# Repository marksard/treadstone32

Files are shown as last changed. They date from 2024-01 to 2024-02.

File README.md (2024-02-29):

# treadstone32
A 32-key compact keyboard project.  

This repository contains projects from rev2 onward. rev1, lite related projects can be found at the following links.  
[https://github.com/marksard/Keyboards/tree/master](https://github.com/marksard/Keyboards/tree/master)

# Completed example
GHZOivdbcAAUKvy

# Layout
ts40-in-m0ii040-case-concept

# Support software

QMK Firmware  
https://github.com/marksard/qmk_firmware/tree/own_build/keyboards/marksard/treadstone32/rev2

# Build guide

https://github.com/marksard/treadstone32/blob/main/documents/buildguide.md

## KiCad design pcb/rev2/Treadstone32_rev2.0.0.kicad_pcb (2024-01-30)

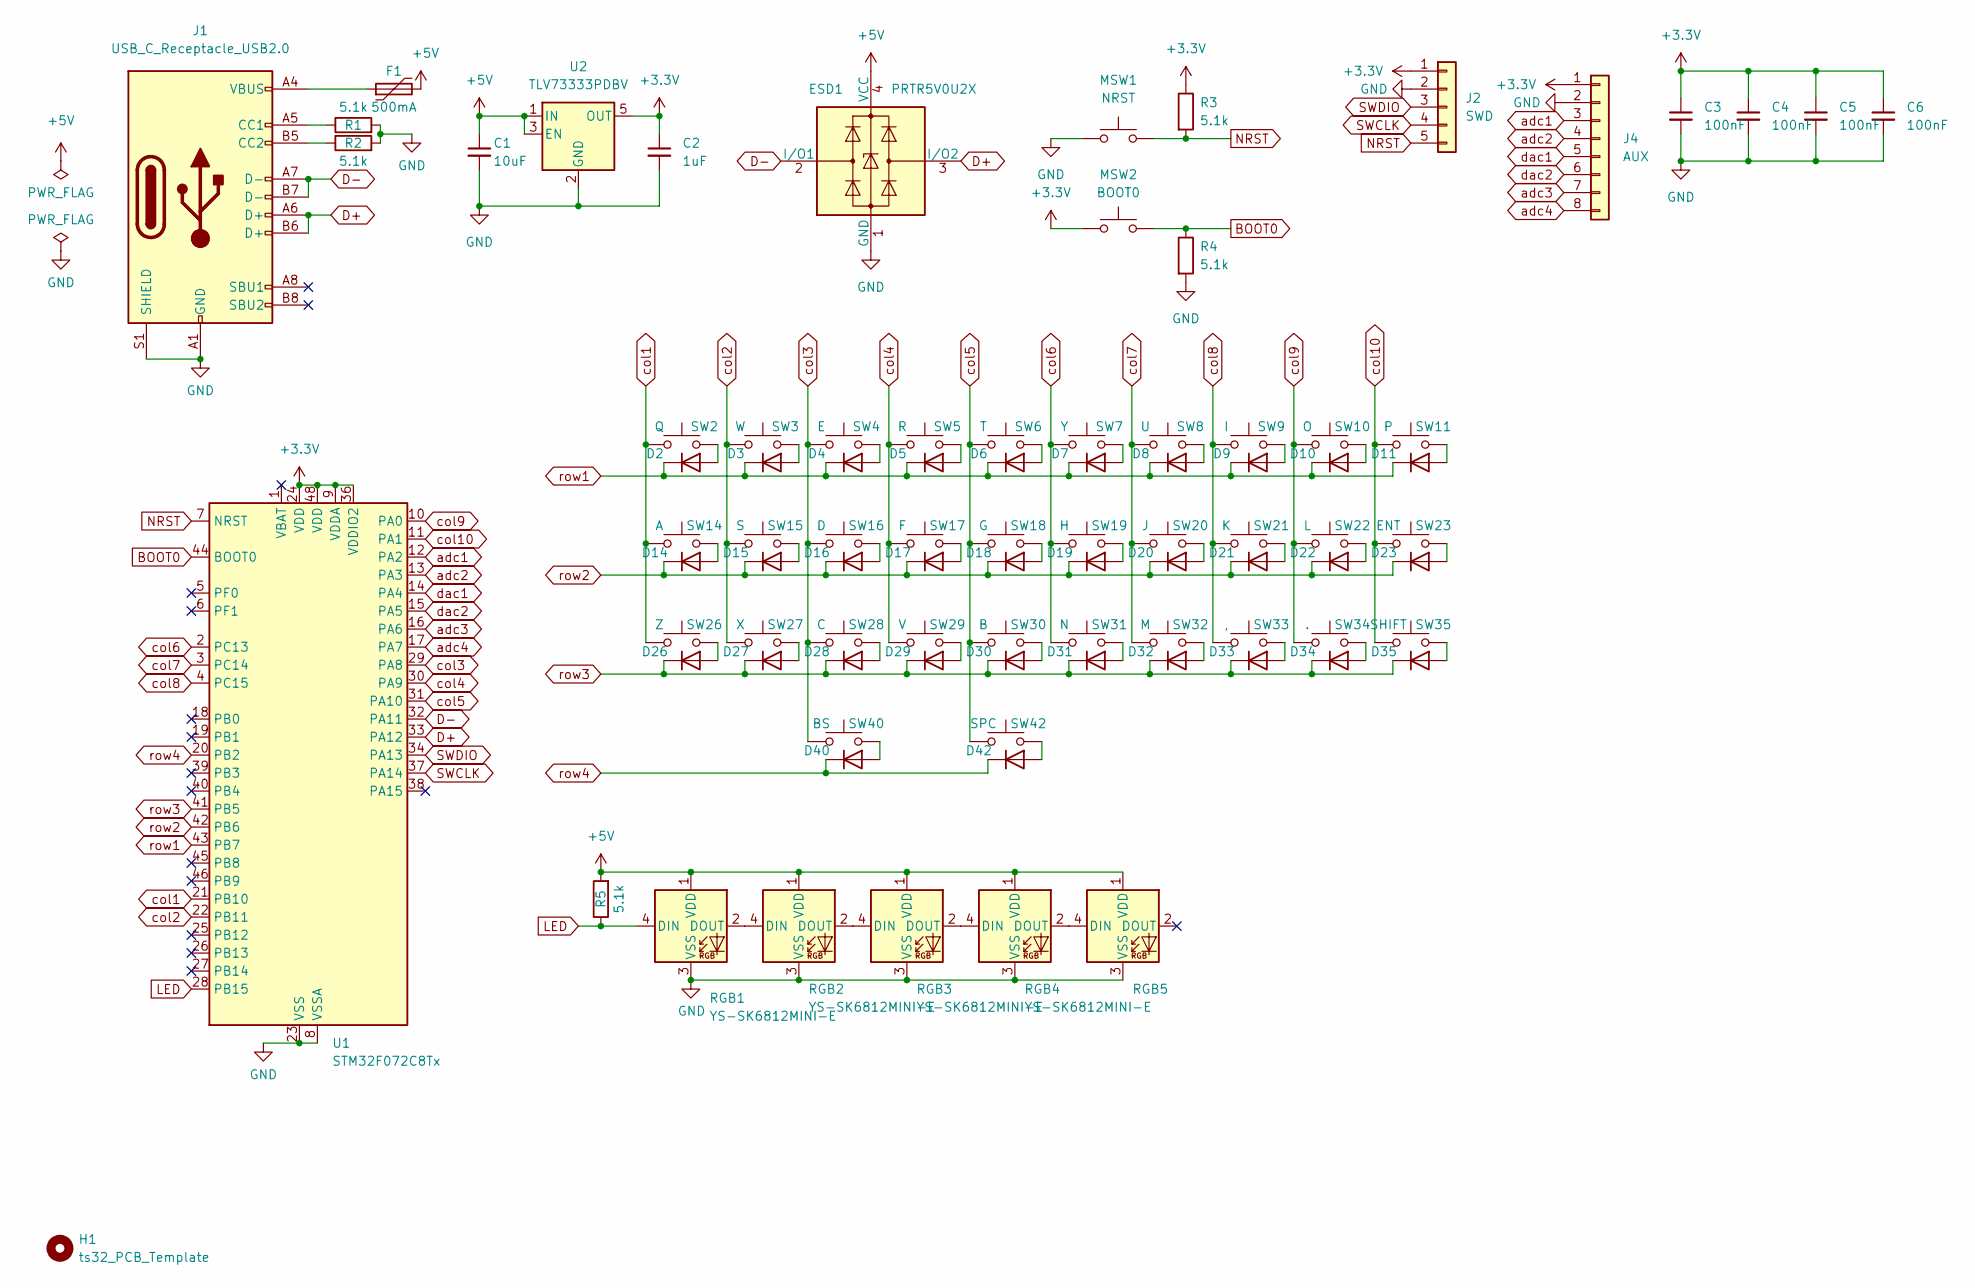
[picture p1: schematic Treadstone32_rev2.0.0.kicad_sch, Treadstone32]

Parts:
C1: 10uF; C_0603_1608Metric; LCSC C19702
C2: 1uF; C_0402_1005Metric; LCSC C52923
C3, C4, C5, C6: 100nF; C_0402_1005Metric; LCSC C1525
D2, D3, D4, D5, D6, D7, D8, D9, D10, D11, D14, D15, D16, D17, D18, D19, D20, D21, D22, D23, D26, D27, D28, D29, D30, D31, D32, D33, D34, D35, D40, D42: D; D_SOD-123; LCSC C81598
ESD1: PRTR5V0U2X; SOT-143; LCSC C12333
F1: 500mA; Fuse_0805_2012Metric; LCSC C261942
H1: ts32_PCB_Template; ts32_PCB_Template_v2.0.0
J1: USB_C_Receptacle_USB2.0; HRO-TYPE-C-31-M-13x; LCSC C2848619
J2: SWD; PinHeader_1x05_P2.54mm_Vertical
J4: AUX; PinHeader_1x08_P2.54mm_Vertical
MSW1: NRST; TVBP06-B043CB
MSW2: BOOT0; TVBP06-B043CB
R1, R2: 5.1k; R_0603_1608Metric; LCSC C23186
R3, R4: 5.1k; R_0402_1005Metric; LCSC C23186
R5: 5.1k; R_0603_1608Metric; LCSC C445832
RGB1, RGB2, RGB3, RGB4, RGB5: YS-SK6812MINI-E; YS-SK6812MINI-E_undergrow; LCSC C5378731
SW2: Q; MX-Hotswap-1U_F; LCSC C5156480
SW3: W; MX-Hotswap-1U_F; LCSC C5156480
SW4: E; MX-Hotswap-1U_F; LCSC C5156480
SW5: R; MX-Hotswap-1U_F; LCSC C5156480
SW6: T; MX-Hotswap-1U_F; LCSC C5156480
SW7: Y; MX-Hotswap-1U_F; LCSC C5156480
SW8: U; MX-Hotswap-1U_F; LCSC C5156480
SW9: I; MX-Hotswap-1U_F; LCSC C5156480
SW10: O; MX-Hotswap-1U_F; LCSC C5156480
SW11: P; MX-Hotswap-1U_F; LCSC C5156480
SW14: A; MX-Hotswap-1U_F; LCSC C5156480
SW15: S; MX-Hotswap-1U_F; LCSC C5156480
SW16: D; MX-Hotswap-1U_F; LCSC C5156480
SW17: F; MX-Hotswap-1U_F; LCSC C5156480
SW18: G; MX-Hotswap-1U_F; LCSC C5156480
SW19: H; MX-Hotswap-1U_F; LCSC C5156480
SW20: J; MX-Hotswap-1U_F; LCSC C5156480
SW21: K; MX-Hotswap-1U_F; LCSC C5156480
SW22: L; MX-Hotswap-1U_F; LCSC C5156480
SW23: ENT; MX-Hotswap-1U_F; LCSC C5156480
SW26: Z; MX-Hotswap-1U_F; LCSC C5156480
SW27: X; MX-Hotswap-1U_F; LCSC C5156480
SW28: C; MX-Hotswap-1U_F; LCSC C5156480
SW29: V; MX-Hotswap-1U_F; LCSC C5156480
SW30: B; MX-Hotswap-1U_F; LCSC C5156480
SW31: N; MX-Hotswap-1U_F; LCSC C5156480
SW32: M; MX-Hotswap-1U_F; LCSC C5156480
SW33: ,; MX-Hotswap-1U_F; LCSC C5156480
SW34: .; MX-Hotswap-1U_F; LCSC C5156480
SW35: SHIFT; MX-Hotswap-1U_F; LCSC C5156480
SW40: BS; MX-Hotswap-1U_F; LCSC C5156480
SW42: SPC; MX-Hotswap-1U_F; LCSC C5156480
U1: STM32F072C8Tx; LQFP-48_7x7mm_P0.5mm; LCSC C80488
U2: TLV73333PDBV; SOT-23-5; LCSC C134139

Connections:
+3.3V: C2.1, C3.1, C4.1, C5.1, C6.1, J2.1, J4.1, MSW2.1, R3.1, U1.9 (VDDA), U1.24 (VDD), U1.36 (VDDIO2), U1.48 (VDD), U2.5 (OUT)
+5V: C1.1, ESD1.4 (VCC), F1.2, R5.2, U2.1 (IN), U2.3 (EN); also elsewhere on the board
BOOT0: MSW2.2, R4.1, U1.44 (BOOT0)
D+: ESD1.3 (I/O2), J1.A6 (D+), J1.B6 (D+), U1.33 (PA12)
D-: ESD1.2 (I/O1), J1.A7 (D-), J1.B7 (D-), U1.32 (PA11)
GND: C1.2, C2.2, C3.2, C4.2, C5.2, C6.2, ESD1.1 (GND), J1.A1 (GND), J1.A12 (GND), J1.B1 (GND), J1.B12 (GND), J1.S1 (SHIELD), J2.2, J4.2, MSW1.1, R1.2, R2.2, R4.2, U1.8 (VSSA), U1.23 (VSS), U1.35 (VSS), U1.47 (VSS), U2.2 (GND); also elsewhere on the board
LED: R5.1, U1.28 (PB15); also elsewhere on the board
NRST: J2.5, MSW1.2, R3.2, U1.7 (NRST)
unnamed: D2.2 (A), SW2.2
unnamed: D3.2 (A), SW3.2
unnamed: D4.2 (A), SW4.2
unnamed: D5.2 (A), SW5.2
unnamed: D6.2 (A), SW6.2
unnamed: D7.2 (A), SW7.2
unnamed: D8.2 (A), SW8.2
unnamed: D9.2 (A), SW9.2
unnamed: D10.2 (A), SW10.2
unnamed: D11.2 (A), SW11.2
unnamed: D14.2 (A), SW14.2
unnamed: D15.2 (A), SW15.2
unnamed: D16.2 (A), SW16.2
unnamed: D17.2 (A), SW17.2
unnamed: D18.2 (A), SW18.2
unnamed: D19.2 (A), SW19.2
unnamed: D20.2 (A), SW20.2
unnamed: D21.2 (A), SW21.2
unnamed: D22.2 (A), SW22.2
unnamed: D23.2 (A), SW23.2
unnamed: D26.2 (A), SW26.2
unnamed: D27.2 (A), SW27.2
unnamed: D28.2 (A), SW28.2
unnamed: D29.2 (A), SW29.2
unnamed: D30.2 (A), SW30.2
unnamed: D31.2 (A), SW31.2
unnamed: D32.2 (A), SW32.2
unnamed: D33.2 (A), SW33.2
unnamed: D34.2 (A), SW34.2
unnamed: D35.2 (A), SW35.2
unnamed: D40.2 (A), SW40.2
unnamed: D42.2 (A), SW42.2
unnamed: F1.1, J1.A4 (VBUS), J1.A9 (VBUS), J1.B4 (VBUS), J1.B9 (VBUS)
unnamed: J1.A5 (CC1), R1.1
unnamed: J1.B5 (CC2), R2.1
SWCLK: J2.4, U1.37 (PA14)
SWDIO: J2.3, U1.34 (PA13)
adc1: J4.3, U1.12 (PA2)
adc2: J4.4, U1.13 (PA3)
adc3: J4.7, U1.16 (PA6)
adc4: J4.8, U1.17 (PA7)
col1: SW2.1, SW14.1, SW26.1, U1.21 (PB10)
col2: SW3.1, SW15.1, SW27.1, U1.22 (PB11)
col3: SW4.1, SW16.1, SW28.1, SW40.1, U1.29 (PA8)
col4: SW5.1, SW17.1, SW29.1, U1.30 (PA9)
col5: SW6.1, SW18.1, SW30.1, SW42.1, U1.31 (PA10)
col6: SW7.1, SW19.1, SW31.1, U1.2 (PC13)
col7: SW8.1, SW20.1, SW32.1, U1.3 (PC14)
col8: SW9.1, SW21.1, SW33.1, U1.4 (PC15)
col9: SW10.1, SW22.1, SW34.1, U1.10 (PA0)
col10: SW11.1, SW23.1, SW35.1, U1.11 (PA1)
dac1: J4.5, U1.14 (PA4)
dac2: J4.6, U1.15 (PA5)
row1: D2.1 (K), D3.1 (K), D4.1 (K), D5.1 (K), D6.1 (K), D7.1 (K), D8.1 (K), D9.1 (K), D10.1 (K), D11.1 (K), U1.43 (PB7)
row2: D14.1 (K), D15.1 (K), D16.1 (K), D17.1 (K), D18.1 (K), D19.1 (K), D20.1 (K), D21.1 (K), D22.1 (K), D23.1 (K), U1.42 (PB6)
row3: D26.1 (K), D27.1 (K), D28.1 (K), D29.1 (K), D30.1 (K), D31.1 (K), D32.1 (K), D33.1 (K), D34.1 (K), D35.1 (K), U1.41 (PB5)
row4: D40.1 (K), D42.1 (K), U1.20 (PB2)

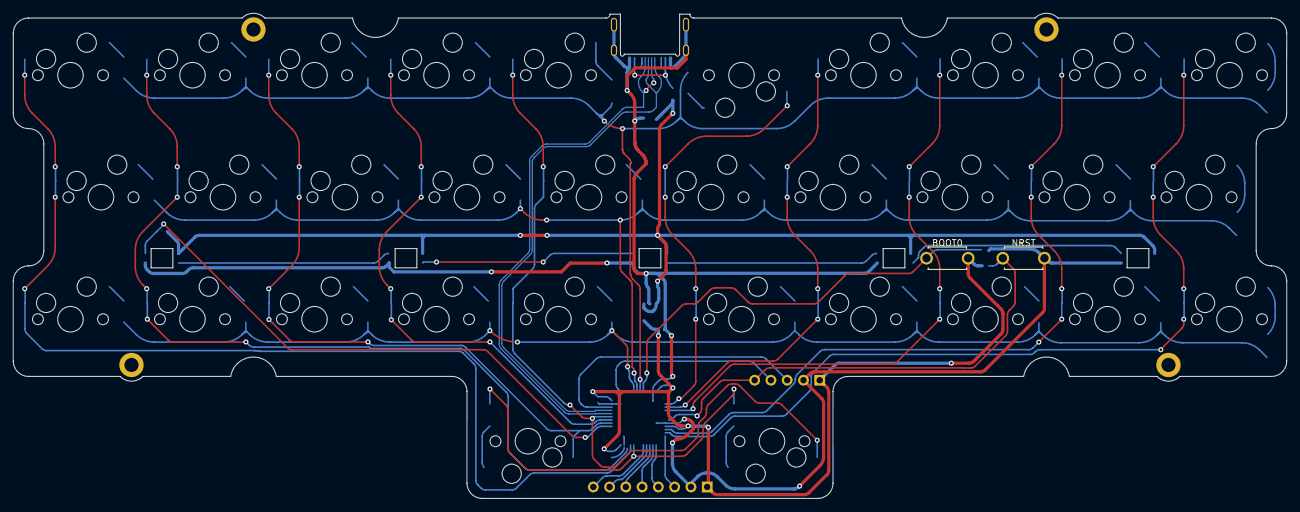
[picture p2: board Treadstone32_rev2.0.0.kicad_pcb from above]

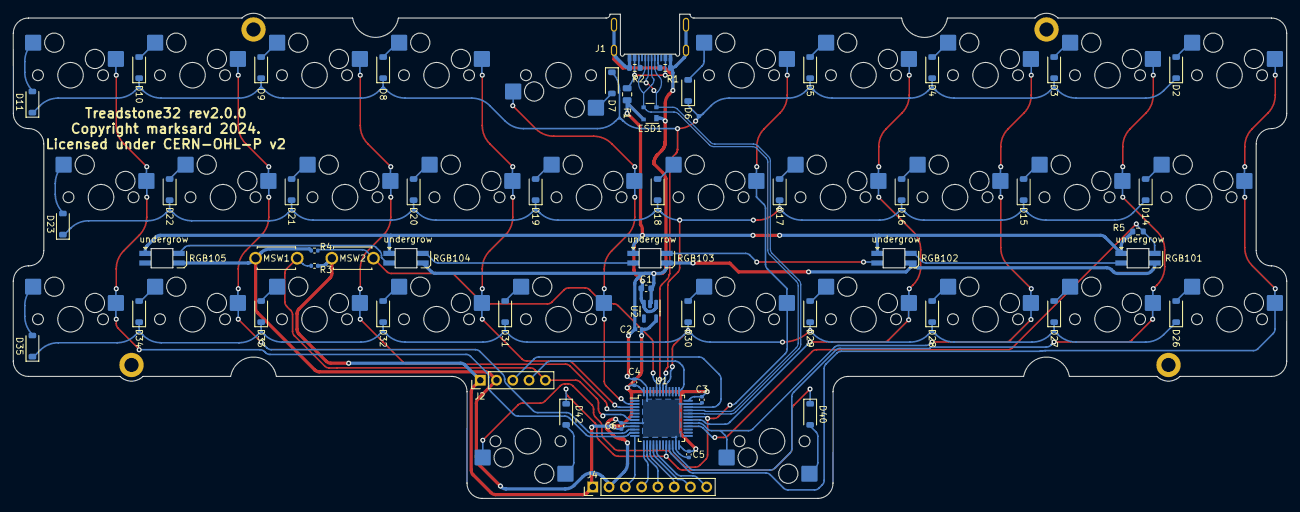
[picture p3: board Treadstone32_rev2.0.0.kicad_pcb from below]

Board: 2 copper layers, 198.8 x 75.8 mm, 90 parts (89 on the bottom side), 69 nets.

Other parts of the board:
RGB101, RGB102, RGB103, RGB104, RGB105: YS-SK6812MINI-E; YS-SK6812MINI-E_undergrow

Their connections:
+5V: RGB101.1 (VDD), RGB102.1 (VDD), RGB103.1 (VDD), RGB104.1 (VDD), RGB105.1 (VDD); also elsewhere on the board
GND: RGB101.3 (VSS), RGB102.3 (VSS), RGB103.3 (VSS), RGB104.3 (VSS), RGB105.3 (VSS); also elsewhere on the board
LED: RGB101.4 (DIN); also elsewhere on the board
unnamed: RGB101.2 (DOUT), RGB102.4 (DIN)
unnamed: RGB102.2 (DOUT), RGB103.4 (DIN)
unnamed: RGB103.2 (DOUT), RGB104.4 (DIN)
unnamed: RGB104.2 (DOUT), RGB105.4 (DIN)

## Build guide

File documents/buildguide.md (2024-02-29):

# Build guide (ビルドガイド)

## The kit includes (キット内容)

|no|name|qty|description|
|:--|:--|:--|:--|
|-|Treadstone32 PCB|1|The keyboard PCB|
|-|Treadstone32 Plate|1|FR4 Switch Plate|
|MSW1|TVBP06-B043CB|1|MCU Reset Switch|
|MSW2|TVBP06-B043CB|1|MCU Boot0 Switch|
|-|Treadstone32 Case|1||
|-|M2 4mm|4||
|-|Rubber Feet|4||

## What needs to be purchased separately (choose your favorite) (キットに含まれません)

|no|name|qty|description|
|:--|:--|:--|:--|
|-|MX Switches|32|As you like|
|-|Keycap set|-|As you like|
|RGB101-105|YS-SK6812MINI-E|5|As you like|

## Installation

1. Place the two tact switches (TVBP06-B043CB) on the PCB side of the photo, in the yellow frame, on the side marked NRST and BOOT0 on the PCB and solder them. (It is possible to use it even if you just fit it in.)
1. The head of the switch will appear in the yellow frame on the side of the plate in the photo, so align the plate with that orientation.
1. Insert the switch into the plate in the four places on the edge. Note that the direction of the switch in the red frame is different from the other parts.
1. Insert the switch into the socket, overlapping the plate and PCB, making sure that the switch pins are not bent or oriented incorrectly.
1. Install the remaining switches onto the plate and into the socket, taking care that the pins of the switches are not bent and that they are not oriented incorrectly.
1. Connect to the PC and verify that it is recognized.
1. If it seems to be interfering with the case, shave off the green part a little and attach it to the case with M2 screws.
1. Attach the rubber feet to the case.

---

1. 写真のPCB側、黄色枠に２つのタクトスイッチ（TVBP06-B043CB）をPCBのNRST、BOOT0と書かれたほうに載せてハンダ付けしてください。（はめ込むだけでも一応使えます）
1. 写真のプレート側、黄色枠にスイッチの頭がでますので、プレートをその向きに合わせます。
1. プレートにスイッチを端の4か所に差し込みます。赤い枠部分はスイッチの向きがほかと違いますので注意してください。
1. スイッチのピンが曲がっていないか、向きが間違っていないか注意して、プレートとPCBを重ねてソケットに差し込んでください。
1. スイッチのピンが曲がっていないか、向きが間違っていないか注意して、残りのスイッチをプレートとソケットに取り付けてください。
1. PCと接続し、認識されることを確認してください。
1. ケースに干渉しているようであれば、緑の箇所を少し削って、M2ネジでケースに取り付けてください。
1. ラバーの足をケースにとりつけてください。

---

20240229_IMGP8666

## Edit the keymap

Remap-compatible firmware has already been written to this PCB.  
You can change the keymap by accessing the following URL.  

以下のURLにアクセスし、キーマップを変更出来ます。  

[remap](https://remap-keys.app/)

## Firmware binary file

You can update the firmware by accessing the following URL.  
Usually it will not be necessary to do so.  

以下のURLにアクセスし、最新のファームウェアをアップデート出来ます。通常はそれを行う必要はないでしょう。  

[firmware](https://remap-keys.app/catalog/lVp2yaV5VNl1xikIcUGL/firmware)

## Bootloader Mode

### Method 1 (方法その1)

While pressing down the Escape key, connect to the PC.  
Escapeキーを押下しながら、PCと接続します。  

### Method 2 (方法その2)

Connect the keyboard to the PC and operate the tact switch attached to the keyboard in the following order:

1. Hold down the BOOT0 button and press the NRST button.  
2. Release the NRST button, then release the BOOT0 button.  

ＰＣにキーボードを接続し、キーボードに取り付けたタクトスイッチを以下の順に操作します。

1. BOOT0ボタンを押したまま、NRSTボタンを押します。
2. NRSTボタンを離してから、BOOT0ボタンを離します。

## If you need help

Twitter: @marksard
Discord: marksard

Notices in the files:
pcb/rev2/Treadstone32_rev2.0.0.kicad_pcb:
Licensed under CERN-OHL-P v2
